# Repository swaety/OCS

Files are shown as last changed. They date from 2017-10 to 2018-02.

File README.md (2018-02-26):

S**MA**RT**IL**

# Boite aux lettres connectées

## **Groupe**

* ABDELKADER Ibrahim, [ibrahim.abdelkader@etu.unice.fr](mailto:ibrahim.abdelkader@esprit.tn), IAM

* BOUDAB Jonathan, [jonathan.boudab@etu.unice.fr](mailto:jonathan.boudab@etu.unice.fr), IAM

* CHALTE Thomas,  [thomas.chalte@etu.unice.fr](mailto:thomas.chalte@etu.unice.fr), IAM

## **Scénarios d’utilisation**

### Définition d’un utilisateur type du système : 

Bob est une personne lambda qui attend souvent pour son courrier. Il va régulièrement à sa boîte aux lettres mais il aimerait ne pas y aller pour rien. De ce fait, il aimerait pouvoir savoir si le facteur est passé ou non. De même Bob, étant souvent sur son lieu de travail aimerait pouvoir jeter un coup d’oeil au contenu de sa boîte aux lettres afin d'être informé plus précisément de son contenu. De plus comme Bob travaille beaucoup, il n’a pas vraiment le temps de se déplacer et d’aller à la poste, ainsi il souhaiterait pouvoir recevoir tous ses colis et lettres contre signature sans avoir à être présent. Enfin, il aimerait surtout pouvoir envoyer ses colis et ses lettres bien plus facilement que ce qui n’existe à l’heure actuelle; c’est à dire, les laisser dans sa boite aux lettres et que le facteur se charge de la transmission pour envoie.

Charles est une personne à mobilité réduite, il  du mal à se déplacer tous les jours à sa boîte aux lettres pour finalement voir son contenu vide, cependant il est obligé de s’y déplacer régulièrement car il reçoit régulièrement des lettres importantes. Charles aimerait pouvoir notifier sa famille proche lors du passage du facteur afin que lors de ses visites on puisse lui relever le courrier.

Dominique est un responsable de la Poste. Il souhaite pouvoir optimiser les tournées de ses facteurs. En effet la démographie d’une ville est en constante évolution et il faut toujours adapter les parcours de chaque facteur pour optimiser le temps de travail.

## Un bon vers le futur ?

Par souci de courrier mouillé, la boite aux lettre sera équipé d’un capteur d’humidité, de température et sera reliée à une API météo afin de prévenir ses utilisateurs que la météo capricieuse risque de détériorer le contenu de sa boite aux lettre.

Enfin pour un futur toujours plus propre, nous pourrions proposer comme option sur notre Smartil, de rajouter un mini panneau solaire afin de l’alimenter en énergie électrique.

## **Équipement TIC**

### Capteurs et actionneurs

<table>
  <tr>
    <td>Nom</td>
    <td>Plateforme</td>
    <td>Prix unitaire</td>
    <td>Qte</td>
    <td>Références</td>
  </tr>
  <tr>
    <td>Capteur de force</td>
    <td></td>
    <td>16.50€</td>
    <td>1</td>
    <td>https://www.gotronic.fr/art-capteur-de-force-adaptateur-1131-12151.htm</td>
  </tr>
  <tr>
    <td>LED RGB</td>
    <td>--</td>
    <td>4.20€</td>
    <td>1</td>
    <td>https://www.gotronic.fr/art-led-8-mm-rgb-grove-104030006-19000.htm</td>
  </tr>
  <tr>
    <td>Bouton-poussoir</td>
    <td>--</td>
    <td>1.99€</td>
    <td>1</td>
    <td>https://www.gotronic.fr/art-module-bouton-grove-101020003-19052.htm</td>
  </tr>
  <tr>
    <td>Raspberry Pi 3</td>
    <td>Raspbian</td>
    <td>24.9€</td>
    <td>1</td>
    <td>https://www.gotronic.fr/art-carte-raspberry-pi3-b-1-gb-24532.html</td>
  </tr>
  <tr>
    <td>GrovePi+</td>
    <td>--</td>
    <td>36.95€</td>
    <td>1</td>
    <td>https://www.gotronic.fr/art-module-grovepi-103010002-23075.htm</td>
  </tr>
  <tr>
    <td>Carte SD </td>
    <td>--</td>
    <td>9.80€</td>
    <td>1</td>
    <td>Transcend 16GB microSDHC</td>
  </tr>
  <tr>
    <td>accéléromètre 3 axes</td>
    <td></td>
    <td>10.40€</td>
    <td>1</td>
    <td>https://www.gotronic.fr/art-module-accelerometre-3-axes-grove-101020039-23846.htm</td>
  </tr>
  <tr>
    <td>Détecteur de distance IR</td>
    <td></td>
    <td>6.20€</td>
    <td>1</td>
    <td>https://www.gotronic.fr/art-detecteur-de-distance-ir-grove-101020175-26434.htm</td>
  </tr>
</table>

## **Planning et Gantt**

[Gantt](/Gantt.xlsx)

## **Maquette Solidworks**

[Maquette Solidworks](/Solidworks/README.md)

## **Sprint**

### **Sprint 0**

**Etudes des capteurs et actionneurs**

[Etude des capteurs et actionneurs](/EtudesCapteurs/etudes.md)

[Pièces commandées](/Pieces_commandees.xlsx)

### **Sprint 1**

[Prototype](/Sprint1_mqtt/readme.md)

### **Sprint 2**

[Avancée du travail](/Sprint2/readme.md)

### **Sprint 3**

[Présentation finale](/Sprint3/readme.md)

## **Devis et Démarchage des entreprises pour la création**

[Devis](/Devis_projet/readme.md)

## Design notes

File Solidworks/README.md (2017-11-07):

# Croquis

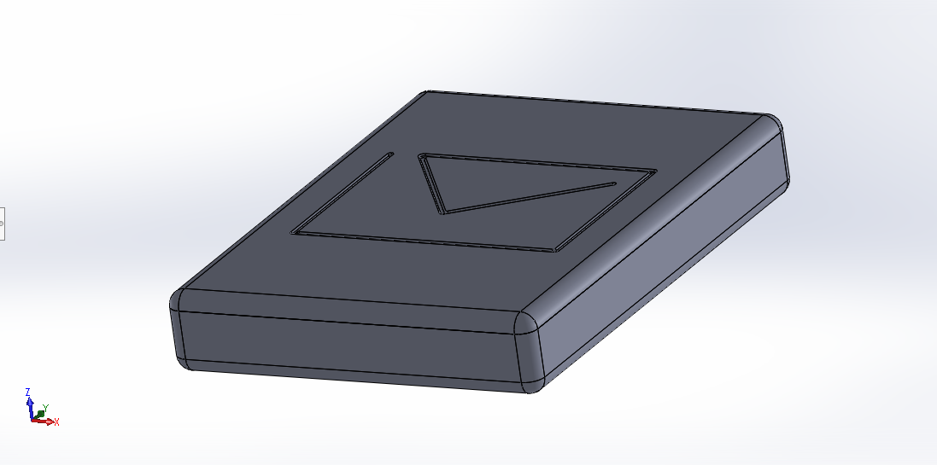
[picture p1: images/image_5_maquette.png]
image alt text


Croquis Solidworks

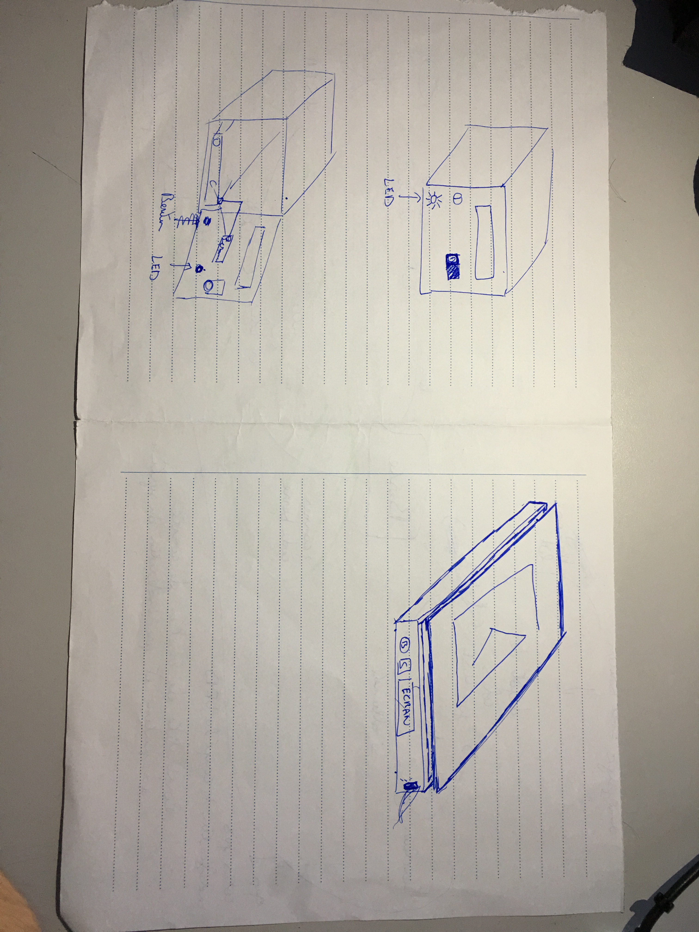
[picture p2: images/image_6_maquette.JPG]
image alt text


Croquis papier

# Maquette Solidworks

Notre design est ergonomique, léger et implémente toutes nos fonctionnalités tout en facilitant l’installation de notre SMARTIL. En effet, il suffit juste d’acheter notre produit et de le placer au fond de n’importe qu’elle boite aux lettres de taille standard pour commencer à l’utiliser.

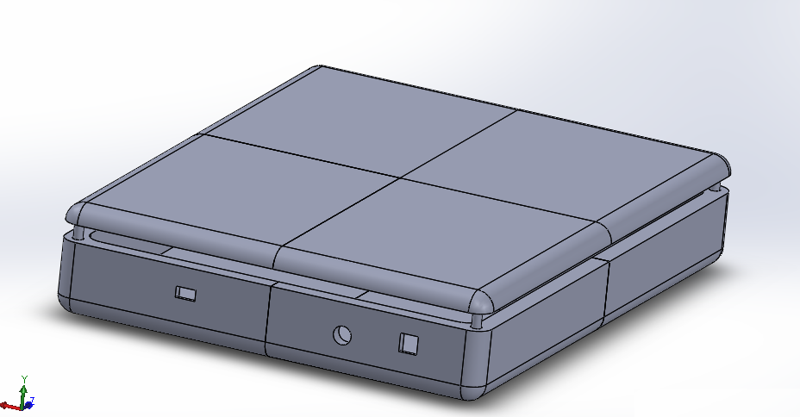
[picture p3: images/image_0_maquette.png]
image alt text


Maquette complète et assemblée

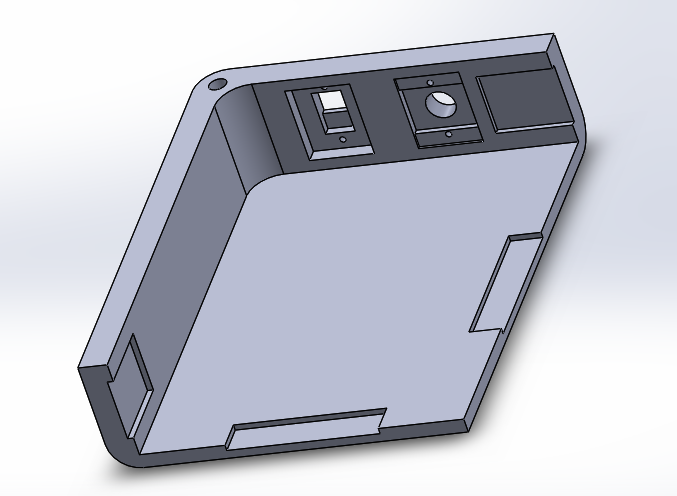
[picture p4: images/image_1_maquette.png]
image alt text


Partie 1 de la maquette avec incorporation de la LED et du bouton

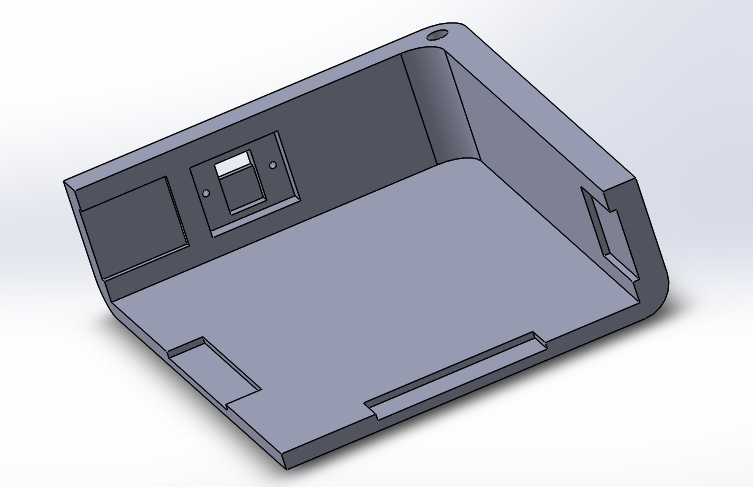
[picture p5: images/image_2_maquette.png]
image alt text


Partie 2 de la maquette avec incorporation du capteur infrarouge

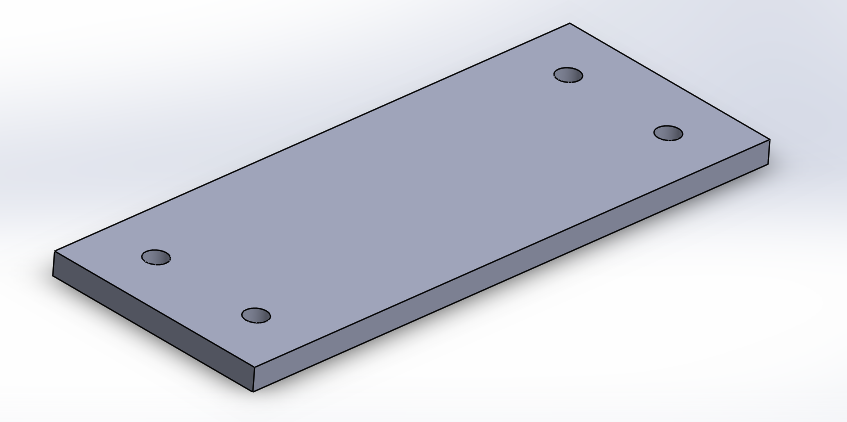
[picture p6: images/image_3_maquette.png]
image alt text


Pièce permettant d’attacher toutes nos parties

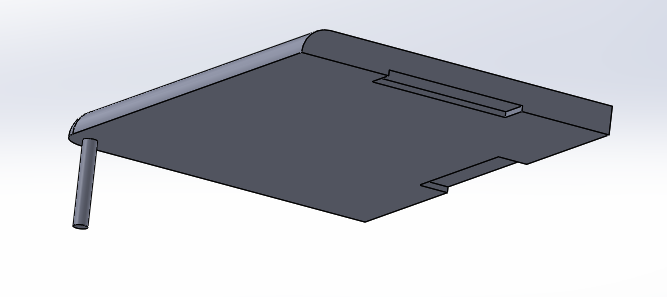
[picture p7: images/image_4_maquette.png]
image alt text


Partie du capot

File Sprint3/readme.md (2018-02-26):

Sprint 3

## Application Mobile

### 	Swift

Nous avons souhaité développer une application mobile pour les clients voulant acheter notre boite aux lettres.

Dans cette application il y a accès à toutes les données utilisateurs ainsi que la gestion des boites aux lettres.

L’application étant développé en swift, elle n’est disponible que sur iOS et donc sur iPhone ou iPad.

### 	Ionic

Dans le même cadre que précédemment, la nécessité d’une application pour vendre un produit fini était nécessaire. De plus, nous ne pouvons nous contenter de viser le public sur iOS. Ainsi nous avons développé une application en Ionic afin de viser le public iOS et le public Android. L’application est opérationnelle. De la même manière que sur l’application codée en Swift, vous pouvez avoir accès à toutes les infos concernant les données utilisateurs ainsi que la gestion des boites.

Actuellement il n’y a pas encore d’application destinée pour la poste et nous ne comptant pas en faire. Nous mettons simplement à disposition nos services pour la poste puisse y avoir accès depuis leur terminaux.

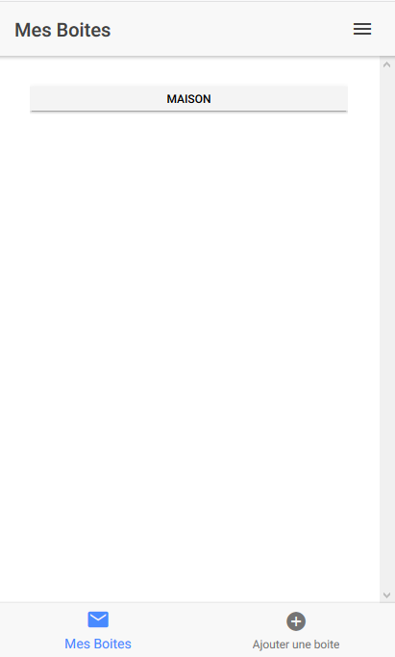
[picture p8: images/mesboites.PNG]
image alt text


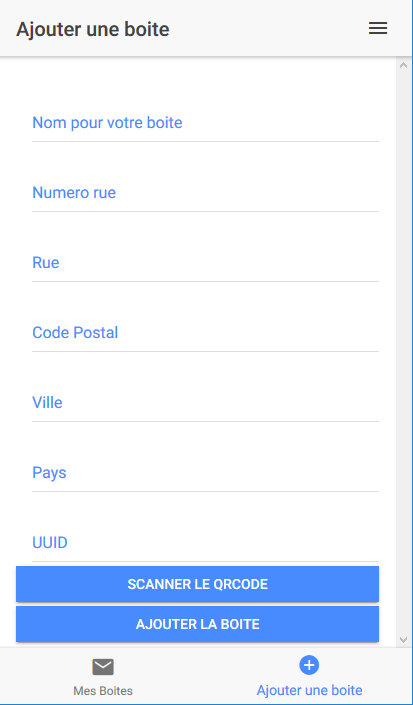
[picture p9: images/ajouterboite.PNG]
image alt text


## Interface Web

Pour toucher le plus de personnes possible, nous avons mis en place notre site web afin d'interagir avec notre produit. Dans cette IHM il y a deux côtés: le premier étant pour les particulier, c’est à dire les personnes qui seront clientes de nos services et donc de notre boite aux lettres. Le deuxième côté est celui destiné à la poste. Avec cette interface, elle pourra voir toutes les données des boîtes aux lettres de ses clients dans son rayon d’action. Ainsi, il y aura une meilleure gestion des relevés de lettres ou de colis chez les particuliers et la poste pourra de la même manière optimiser la tournée de ses facteurs en fonction du temps passé pour la dépose du courrier.

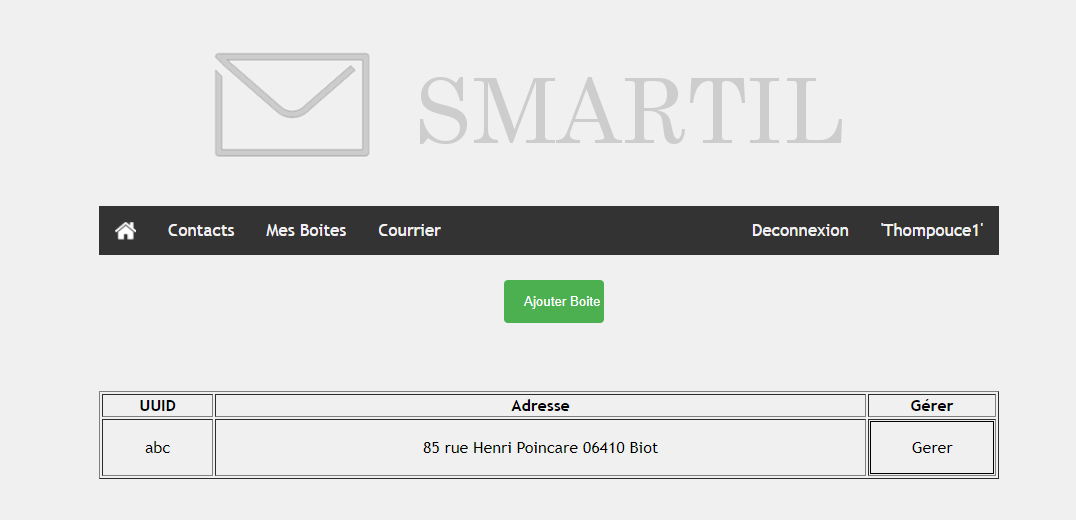
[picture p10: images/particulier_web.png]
image alt text


Exemple de l’interface d’un utilisateur qui a qu’une seule boite.

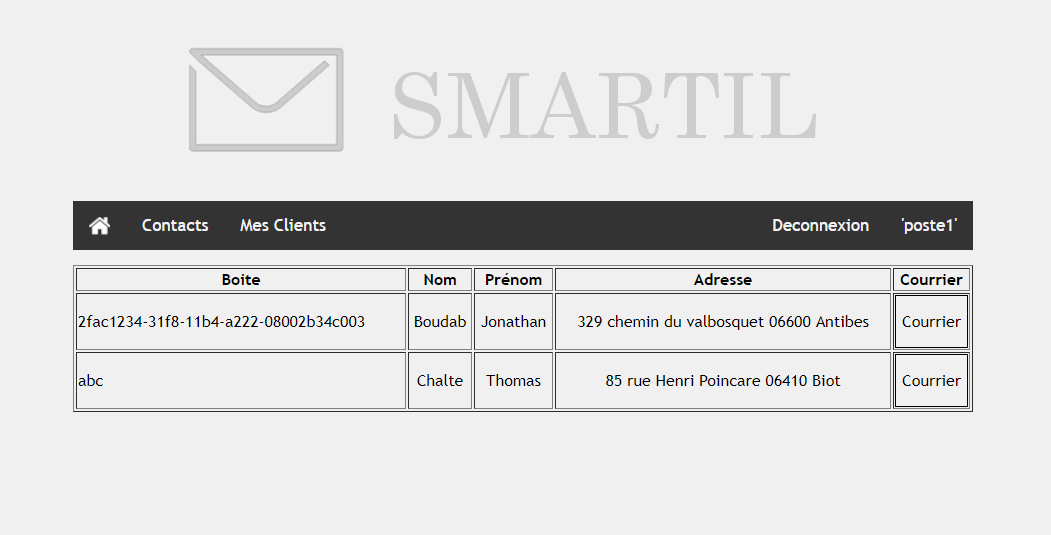
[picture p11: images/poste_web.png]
image alt text


Exemple de l’interface de la poste qui peut gérer tous ses potentiels clients.

## Application Passerelle

Souhaitant vivre avec les technologie de l’avenir, nous avons mis en place une application s’installant directement dans les box de nos futurs clients. Cette application permet de faire le lien entre la boite aux lettres et le serveur de données, qui lui est hébergé dans le cloud.

Cette application est générique. En effet, une fois installée, elle "écoute" tous les objets qu’elle peut voir sur le réseau local en UPnP. Dès lors qu’elle trouve un objet nommé Smartil, la communication commence et le système est prêt à fonctionner.

## Serveur et base de données

Nous avons décidé de mettre en place un serveur de type REST afin de gérer l’intelligence de notre projet. C’est lui que fait la gestion de toutes les informations recueillis dans le sites web, l’application mobile ou bien la boite aux lettres.

Il contact aussi l’API Google Maps afin de gérer le rayon d’action des différentes postes qui utilisent notre service.

Toutes les données sont sauvegardées par le serveur dans une base de données persistante.

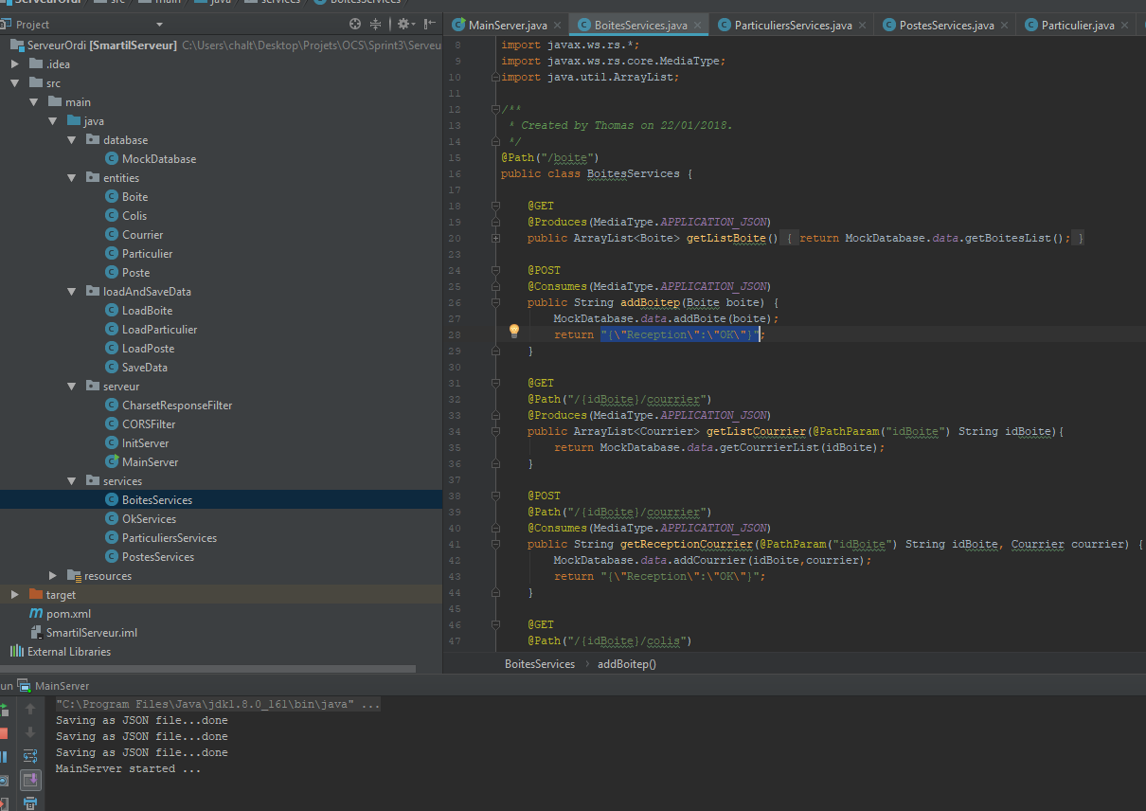
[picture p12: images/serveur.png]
image alt text


## Serveur Raspberry (Boite aux lettres)

Enfin voici l’objet en lui même. Notre boite aux lettres connectées utilisant une raspberry PI 3. 

Dans cet objet nous utilisons le protocole UPnP afin de déployer nos services.

Parmis les services que nous proposons, il y a:

* la notification de la réception de courrier

* l’envoi de courrier par notre boite aux lettres

* la prise du courrier par le facteur

* l’accès à tous les capteurs et actionneurs: LED, bouton, accéléromètre et télémètre infrarouge.

L’objet est très simple d’utilisation, en effet, il suffit de le brancher pour qu’il fonctionne. Il va se connecter automatiquement au réseau wifi disponible afin de déployer ses services. Ces services sont visibles simplement avec l’outils Device Spy et de ce fait, une autre utilisation de nos services est possible.

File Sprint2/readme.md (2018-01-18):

Sprint 2

## Etude de la signature électronique automatique de la boite aux lettres

Nous avons proposé à nos encadrants le fait de faire une signature électronique automatique avec la boite aux lettres lors de la réception du courrier. En effet le facteur apporte un colis ou une lettre à faire signer cependant si la personne n’est pas présente, cela pose problème et il y a une perte de temps autant pour le facteur que pour la personne.

De ce fait nous voulions que le facteur puisse déposer le courrier à faire signer directement dans la boite aux lettres et que celle ci signe avec une signature électronique. 

La solution d’émettre un signal d’une quelconque manière au propriétaire de la boite est une idée qui ne résout pas le problème du temps perdu. En effet le facteur ne peut pas attendre que le propriétaire se prenne le temps de regarder son téléphone par exemple et de signer électroniquement pour qu’il puisse déposer le courrier.

Nos encadrants nous ont malheureusement immédiatement bloqué car nous n’avons pas le droit légalement parlant de faire signer la boite aux lettres à la place d’un humain.

Pour être totalement sur de la faisabilité ou non de ce service dans ce projet nous avons pris contact avec une avocate de Metz. Celle ci nous a confirmé le fait que seule une personne physique peut signer électroniquement et non un objet. Il n’y a pas encore eu de cas de jurisprudence dans ce sens afin de faire évoluer la loi.
Ainsi nous avons dû oublier ce point.

## Optimisation de la boite aux lettres pour la poste

Dans le cadre de ce projet, nous nous sommes présentés à la Poste de Bouzonville afin de parler avec le directeur d’agence. Celui-ci nous a reçu et nous avons pu lui exposer notre projet. Nous lui avons expliqué que si les boites aux lettres étaient toutes équipées de notre système, il pourrait voir le moment de passage de chaque facteur au niveau des boîtes aux lettres. Cette énorme quantité de données pourrait lui permettre d’optimiser la tourner de chaque facteur afin de gagner du temps et de ne pénaliser personne sur la charge de travail.

## Mise en place des services sur la Raspberry

Parmis les deux points précédents, la signature électronique et automatique n’est pas possible, comme précisé dans l’article. Cependant l’optimisation de la boite aux lettres pour la poste est implémentée dedans et est l’un des points les plus importants.

Ensuite vu que ça reste tout de même une boite aux lettres, nous avons intégrer un service permettant de détecter la réception du courrier par l’ajout d’une notification dans la base de données. De plus nous avons choisi de pouvoir poster du courrier avec notre boite aux lettres. Pour se faire, il y aura une diode pour prévenir le facteur qu’il doit prendre ce qu’il y a dans la boite.

Enfin, nous avons mis en place un service à la personne. Celui-ci permet de détecter l’inactivité de la levée du courrier pendant une durée calculée en fonction de la levée habituelle du courrier.

## Mise en place d’un serveur REST

Nous avons décidé de mettre en place un serveur de type REST afin de gérer l’intelligence de notre projet.

Toutes les données sont sauvegardées par le serveur dans une base de données persistante.

## Développement d’un interface web

Pour avoir la meilleure performance possible, nous avons développé une interface web en vanilla JS. Celle ci est assez minimaliste au niveau de design mais suffisante l’utilisabilité de notre projet

url de l’interface bientot disponible

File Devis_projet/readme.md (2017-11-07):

# Devis

## 1. Sculpteo

Afin de réaliser au mieux notre projet, nous aimerions pouvoir réaliser un prototype qui se rapproche au mieux de notre vision de produit final. Notre conception étant plus ou moins compliqué à réaliser par notre lycée partenaire, nous avons pris des initiatives en réalisant un devis au "Lycée Louis Vincent - Metz" dont nous attendons encore les retours (cause de vacances scolaires) et avons réalisé des devis en ligne sur le site sculpteo.fr

Voici les factures que nous avons obtenus : 

Pour notre modèle designé suivant les contrainte du lycée des eucalyptus (coupé en pièces n'excédant pas une feuille A5) : 

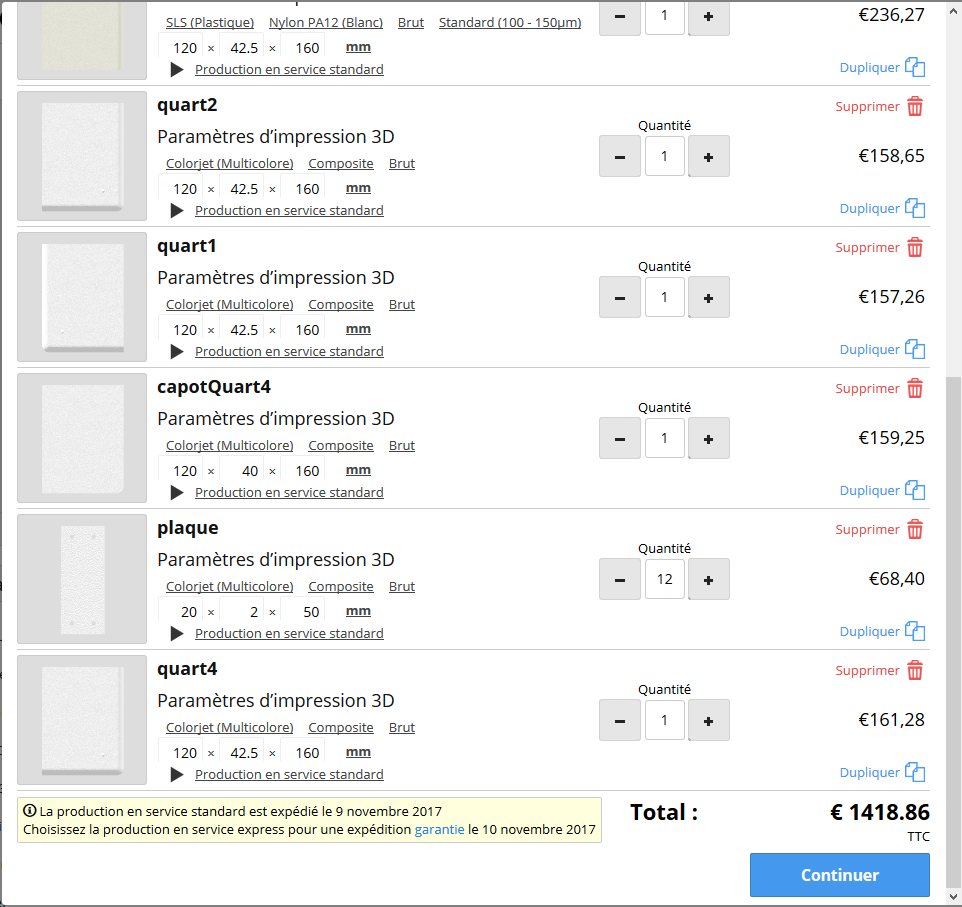
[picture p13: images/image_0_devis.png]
image alt text


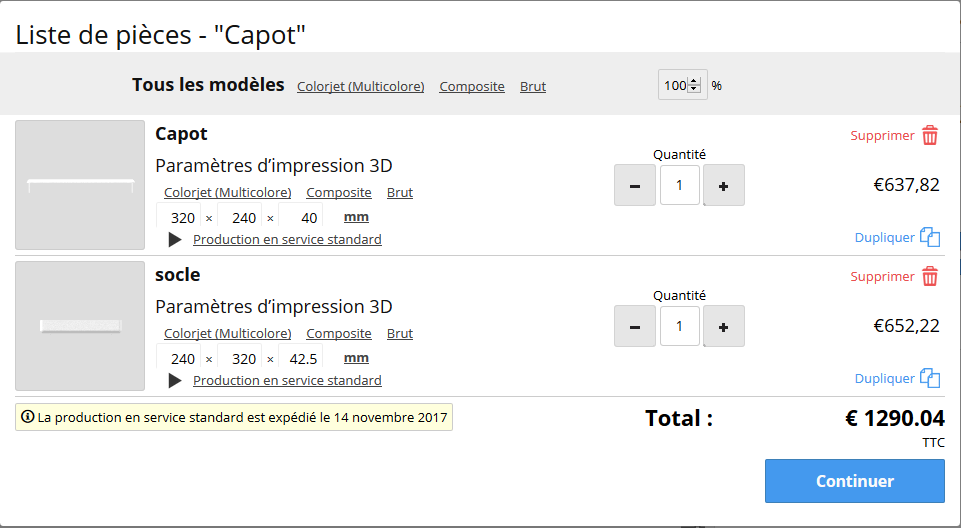
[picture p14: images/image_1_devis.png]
image alt text
Pour notre modèle designé ne suivant aucune contrainte :

## 2.  Louis Vincent

En attente de réponse

## 3. Conclusion

Pour conclure sur ce sujet, faire réaliser notre maquette sur un site externe est irréalisable, en effet la facture colossale obtenue ne nous sera jamais accordée et semble être un point bloquant sur notre vision du produit "accessible au plus grand nombre" 

Nous attendons donc le retour du lycée "Louis Vincent" pour le prix de l’impression débouchant sur un potentiel partenariat avec Polytech.

Nous mettons donc en oeuvre toutes nos capacités et facultés afin de pouvoir réaliser ce projet de la partie logicielle à la partie mécanique afin que nous arrivions à un produit final de bonne qualité et conforme à nos attentes.

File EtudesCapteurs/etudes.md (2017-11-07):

# Etude des capteurs et actionneurs

Afin de bien répondre aux besoins fonctionnels de notre boîte aux lettres connectée on aura besoin de deux types de capteurs :

* Un premier capteur pour détecter la présence d’une nouvelle lettre.

* Un deuxième capteur pour détecter l’ouverture et la fermeture de la porte de la boîte aux lettres.

* Enfin il nous faut une LED ainsi qu’un bouton pour pouvoir informer le facteur qu’un colis ou lettre est dans la boîte et qu’il doit le prendre pour l’envoyer.

    Pour le premier point, nos recherches ont révélé les 6 types de capteurs suivants :

Le télémètre : Il n’existe pas de capteur à un prix abordable permettant de faire une mesure de la précision demandée. En effet, pour détecter l'arrivée d’une lettre dans la boîte aux lettres, il faut capter un déplacement du capot de moins d’un millimètre. De plus le deuxième problème était que ce capteur fonctionne qu’à partir d’une distance de 10cm; c’est donc bien trop long pour que nous puissions l’utiliser.

[télémètre](https://www.gotronic.fr/art-capteur-de-mesure-sharp-gp2y0a21yk0f-11539.htm) 
[Desscription complète](/EtudesCapteurs/télémètre.pdf)

Le potentiomètre : Le problème avec ce capteur est qu’il mesure 60 mm de long et donc son positionnement à la vertical est impossible car nous n’avons pas la hauteur nécessaire. De ce fait nous voulions le positionner à l’horizontal au fond de notre boitier mais cela implique de faire une transformation du mouvement vertical en horizontal. Pour éviter les imprécisions liées à notre montage nous avons préféré changer de capteur. 

[potentiomètre](https://www.gotronic.fr/art-potentiometre-a-glissiere-grove-101020036-19012.htm)
[Description complète](https://www.gotronic.fr/art-potentiometre-a-glissiere-grove-101020036-19012.htm#complte_desc)

Le gyroscope : Ce capteur-là agit comme une boussole et il répond partiellement à nos besoins mais l’absence d’un détecteur de mouvement sur son axe vertical le rend inadaptable à notre système.

[gyroscope](https://www.gotronic.fr/art-module-boussole-3-axes-grove-101020034-18955.htm)
[Description complète](https://www.gotronic.fr/art-module-boussole-3-axes-grove-101020034-18955.htm#complte_desc)

Le capteur de collision: Ce capteur semblait très prometteur, cependant après de nombreux tests et une lecture approfondi de la documentation, le capteur ne permet pas une mesure assez fini pour détecter la réception d’une lettre de moins de 20 grammes.

[capteur de collision](https://www.gotronic.fr/art-capteur-de-collision-grove-101020005-23847.htm)
[Description complète](http://wiki.seeed.cc/Grove-Collision_Sensor/)

Le capteur de force : Ce capteur est à étudier, cependant il ne nous semble que très peu adapté à notre système. En effet, nous objet dispose d’une grande surface en mouvement (le capot), ainsi il nous semble difficile d’utiliser qu’un seul capteur de force pour détecter la réception d’une lettre.

[capteur de force](https://www.gotronic.fr/art-capteur-de-force-adaptateur-1131-12151.htm)
[Schéma](/EtudesCapteurs/force.pdf)
[Mode d'emploi](https://www.phidgets.com/docs/1131_User_Guide)

L’accéléromètre : En dernier lieu nous sommes partis sur un accéléromètre pour détecter une accélération à chaque fois qu’une lettre est déposé. Ce capteur nous convient totalement: l’étalonnage des données est bon et surtout la précision est bonne car nous détectons la pose d’une feuille de 5 grammes.

[accéléromètre](https://www.gotronic.fr/art-module-accelerometre-3-axes-grove-101020039-23846.htm)
[Description complète](http://wiki.seeed.cc/Grove-3-Axis_Digital_Accelerometer-1.5g/)

Pour le deuxième point nous avons choisi d’utiliser un capteur de proximité infrarouge afin de détecter l’ouverture et la fermeture de la porte de la boîte aux lettres.

[accéléromètre](https://www.gotronic.fr/art-detecteur-de-distance-ir-grove-101020175-26434.htm)
[Description complète](http://wiki.seeed.cc/Grove-IR_Distance_Interrupter_v1.2/)

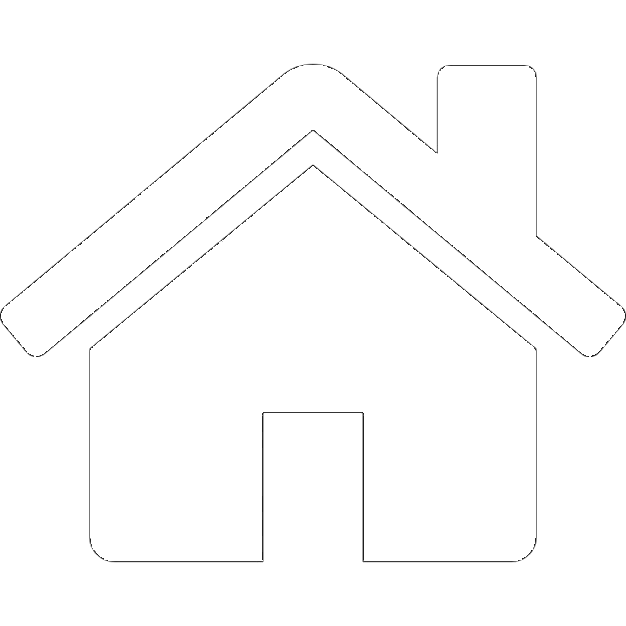
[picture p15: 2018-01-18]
Sprint3/IHMWeb/styles/images/home.png

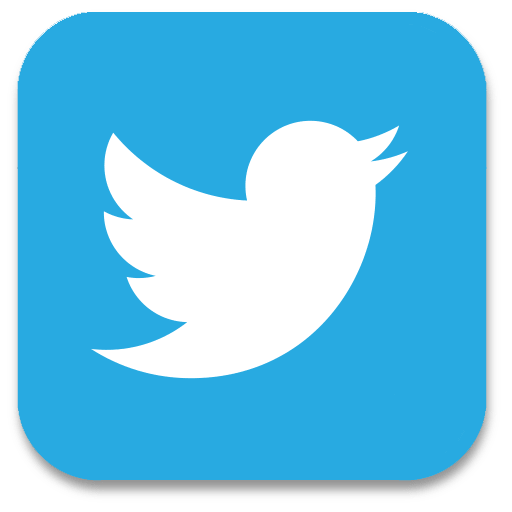
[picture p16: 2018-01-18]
Sprint3/IHMWeb/styles/images/twitter.png

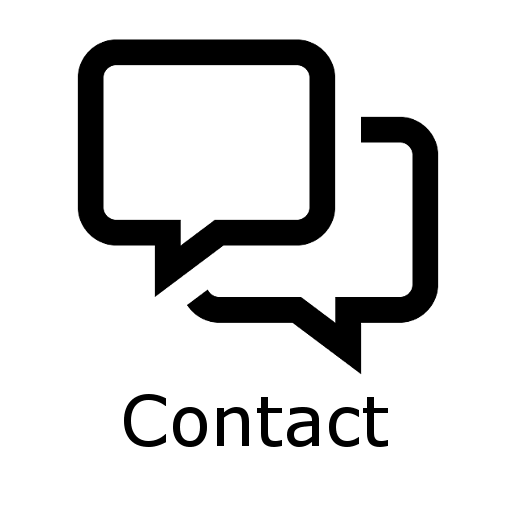
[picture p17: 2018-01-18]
Sprint3/IHMWeb/styles/images/contact.png

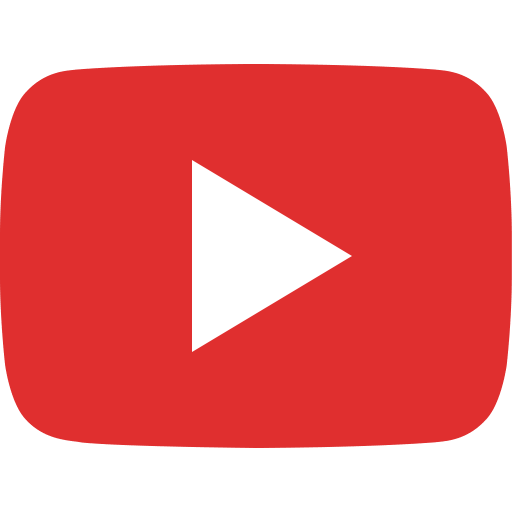
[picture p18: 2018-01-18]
Sprint3/IHMWeb/styles/images/youtube.png

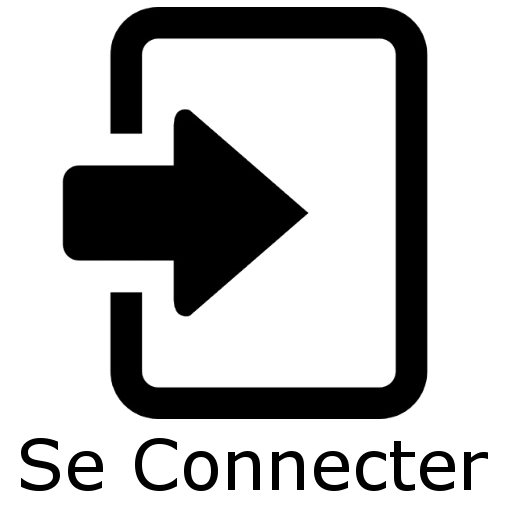
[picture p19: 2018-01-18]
Sprint3/IHMWeb/styles/images/login.png

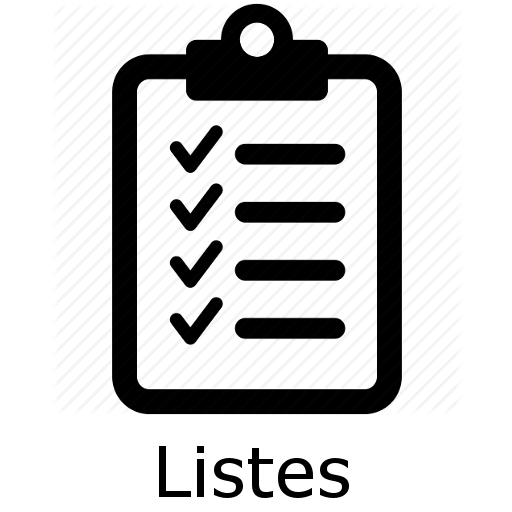
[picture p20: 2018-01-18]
Sprint3/IHMWeb/styles/images/list.png

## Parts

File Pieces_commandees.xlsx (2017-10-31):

Nom Produit | Prix Produit | Nb Produit | Coût Total | URL | Fourni | Commandé |  | Livré |  | Donné | Final
Projet X
Raspberry Pi 3 | 44.95 € | 1 | 44.95 € | https://www.gotronic.fr/art-carte-raspberry-pi3-b-1-gb-24532.htm | oui |  | Oui |  | Oui |  | Oui
Grove Pi+ | 37.21 € | 1 | 37.21 € | https://www.lextronic.fr/P30111-platine-dinterface-grove-pi.html | oui |  | Oui |  | Oui |  | Oui
Capteur de force | 16.50 € | 1 | 16.50 € | https://www.gotronic.fr/art-capteur-de-force-adaptateur-1131-12151.htm | oui |  | Oui |  | Oui |  | Oui
LED RGB | 4.20 € | 1 | 4.20 € | https://www.gotronic.fr/art-led-8-mm-rgb-grove-104030006-19000.htm | oui |  | Oui |  | Oui |  | Oui
Bouton-poussoir | 1.99 € | 1 | 1.99 € | https://www.gotronic.fr/art-module-bouton-grove-101020003-19052.htm | oui |  | Oui |  | Oui |  | Oui
Carte SD | 9.80 € | 1 | 9.80 € |  | oui |  | Oui |  | Oui |  | Oui
accéléromètre 3 axes | 10.40 € | 1 | 10.40 € | https://www.gotronic.fr/art-module-accelerometre-3-axes-grove-101020039-23846.htm | oui |  | Oui |  | Oui |  | Oui
Détecteur de distance IR | 6.20 € | 1 | 6.20 € | https://www.gotronic.fr/art-detecteur-de-distance-ir-grove-101020175-26434.htm | oui |  | Oui |  | Oui |  | Oui
 |  |  | 131.25 €

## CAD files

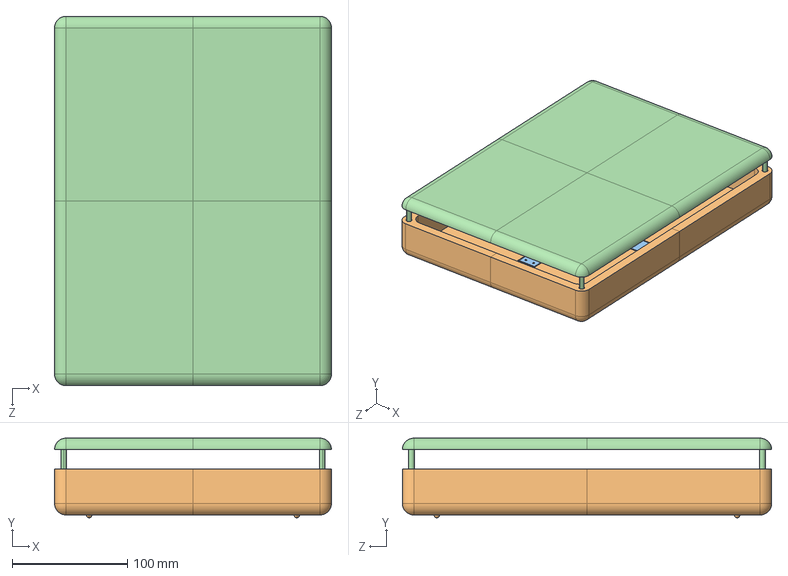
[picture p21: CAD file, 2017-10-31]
Solidworks/Assemblage SMARTIL.STEP
240.0 x 69.0 x 320.0 mm
quart1
quart2
quart3
quart4
plaque x 12
capotQuart1
capotQuart2
capotQuart3
capotQuart4

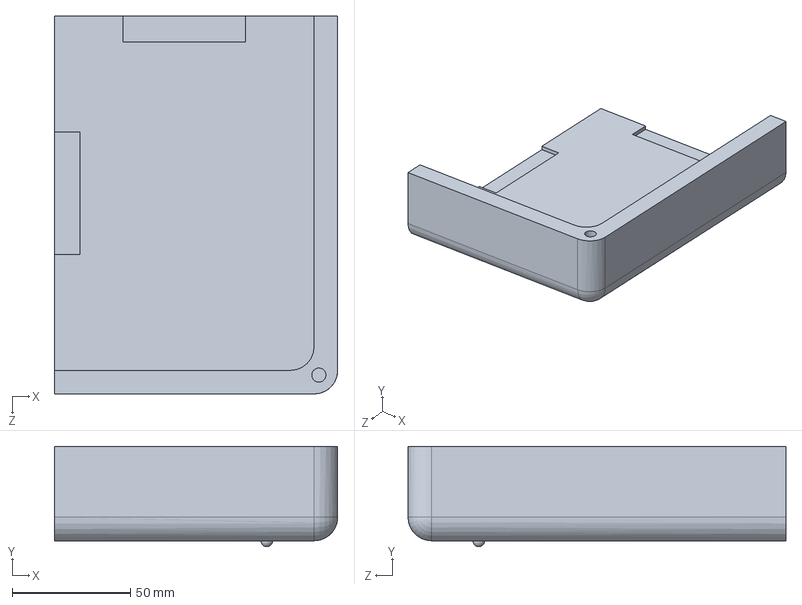
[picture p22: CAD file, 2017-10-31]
Solidworks/quart3.SLDPRT
120.0 x 42.5 x 160.0 mm

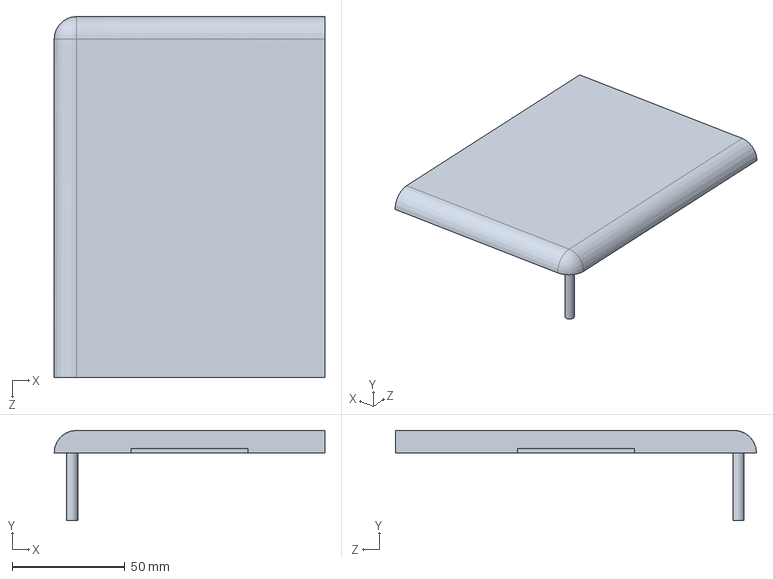
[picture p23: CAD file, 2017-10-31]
Solidworks/capotQuart1.SLDPRT
120.0 x 40.0 x 160.0 mm

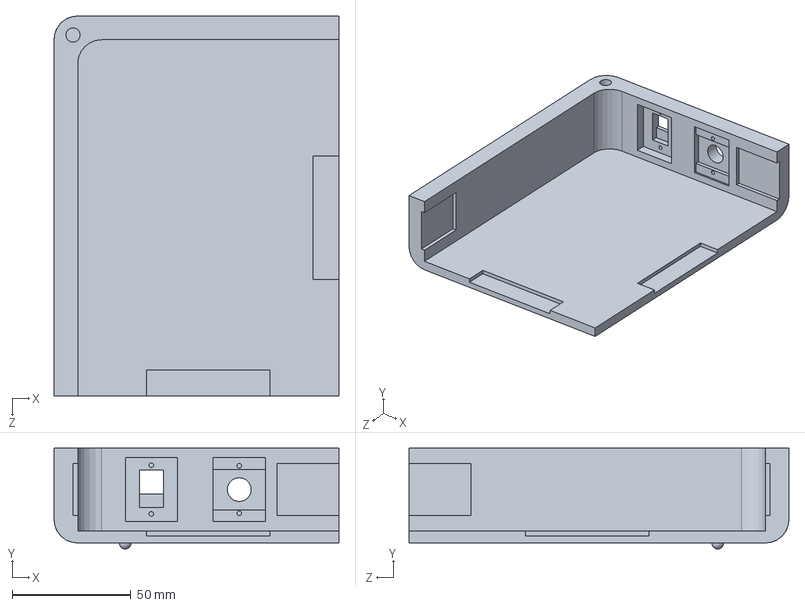
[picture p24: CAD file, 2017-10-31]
Solidworks/quart1.SLDPRT
120.0 x 42.5 x 160.0 mm

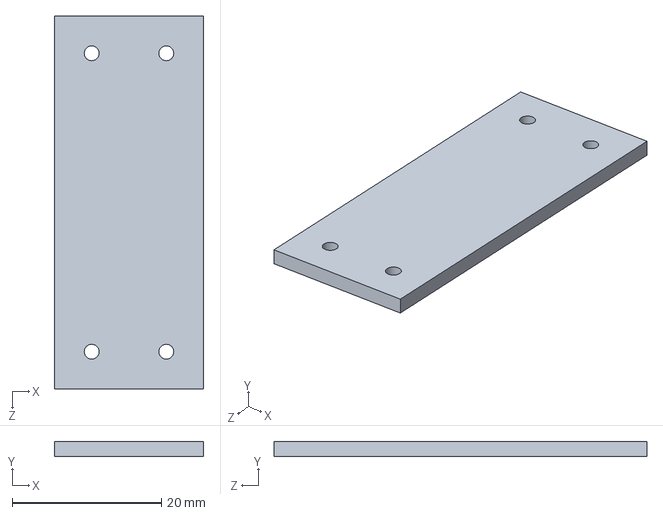
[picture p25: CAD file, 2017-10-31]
Solidworks/plaque.SLDPRT
20.0 x 2.00 x 50.0 mm

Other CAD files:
Solidworks/quart4.SLDPRT
Solidworks/capotQuart4.SLDPRT
Solidworks/capotQuart3.SLDPRT
Solidworks/quart2.SLDPRT
Solidworks/capotQuart2.SLDPRT
Solidworks/Assemblage SMARTIL.SLDASM

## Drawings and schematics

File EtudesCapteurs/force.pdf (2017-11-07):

# 1131_0 Mechanical Drawing

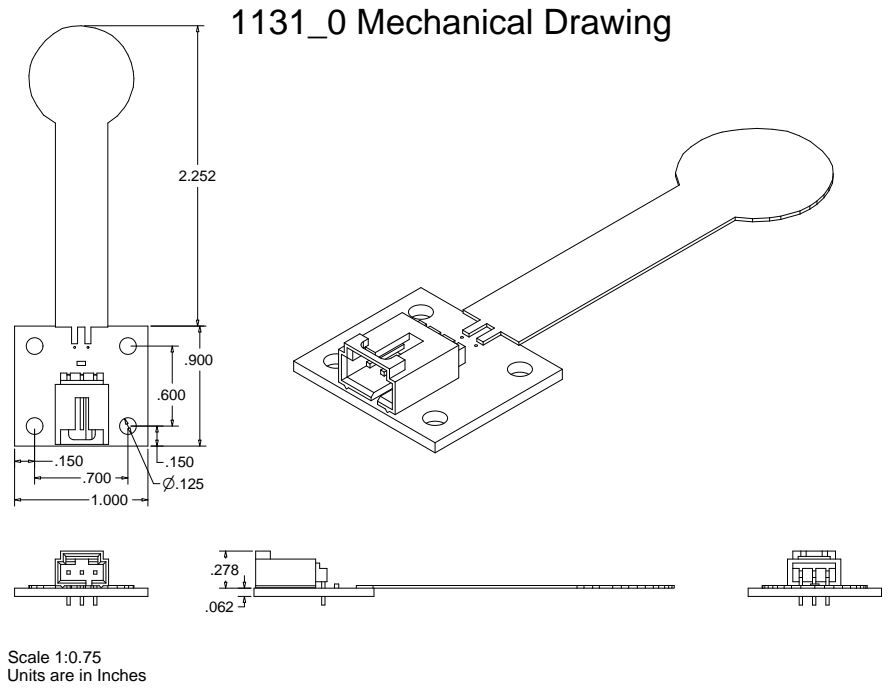
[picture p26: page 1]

Scale 1:0.75
Units are in Inches

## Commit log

2017-10-23 Ajout du Gantt
    [gantt_ocs_17_18.xlsx]
2017-10-24 Websocket and RestApi examples for raspberry pi + groovepi button (sprint1)
2017-10-31 => Configuration et calibrage des capteurs (infrarouge/accéléromètre) avec le bouton poussoir
    => Configuration du protocole MQTT afin de ne publier que les changements d’états des capteurs
2017-10-31 => Configuration du protocole MQTT coté serveur et identification des évènements provenant des différents capteurs.
    => Configuration d’une base de données « MongoDb » et persistance des données dedans lors de la capture d’un nouvel évènement.
    => Configuration d’un service d’envoi de mail avec « Nodemailer » lors de la capture d’un évènement de type ‘nouvelle lettre’.
2017-10-31 Ajout de l'étude des capteurs
2017-10-31 Ajout du solidworks
    [Assemblage SMARTIL.SLDASM, Assemblage SMARTIL.STEP, capotQuart1.SLDPRT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]
2017-10-31 ajout de légende
2017-11-07 Test de réorganisation
    [Assemblage SMARTIL.SLDASM, Assemblage SMARTIL.STEP, Gantt.xlsx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]
2018-01-18 Changement de groupe
2018-01-18 Ajout de l'interface
2018-01-22 Ajout de fonctionnalités
2018-01-22 service de la boite terminés
2018-02-08 base de données
2018-02-11 Bien joué
    [Assemblage SMARTIL.SLDASM, Assemblage SMARTIL.STEP, Gantt.xlsx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]
2018-02-13 Ajout calcul de distance
2018-02-17 Rajout de services
2018-02-17 Mise à jour de l'ihm
2018-02-18 Finalisation de l'IHM
2018-02-24 creer compte avec sauvegarde dans le serveur et obtention des IDs
2018-02-24 courrier avec l'obtention de l'ID du session dans le script
2018-02-24 mes boites updated avec obtention de l'id de la session active
2018-02-24 Mise à jour des retours sur les GET et POST
2018-02-25 Mise à jour du site web sur toutes les pages
2018-02-25 Ajout app ionic croos plateform ok ios et android
2018-02-26 Réorganisation du git Mise à jour de la base de données
    Pret pour la démo
